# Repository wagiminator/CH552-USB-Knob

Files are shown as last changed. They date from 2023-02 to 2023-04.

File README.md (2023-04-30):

# CH552E USB Knob - Rotary Encoder with USB Interface
The USB Knob is a versatile device that combines the functionality of a rotary encoder with the convenience of a USB interface. It is based on either the CH552E or CH554E microcontroller and is equipped with addressable LEDs, commonly known as NeoPixels. The unique combination of these components makes the USB Knob an ideal choice for a wide range of applications, including volume control for PCs.

One of the standout features of the USB Knob is that it requires no driver installation, making it incredibly easy to use. The device acts as a USB human interface device (HID), meaning that it can be recognized and utilized by most computers without the need for additional software.

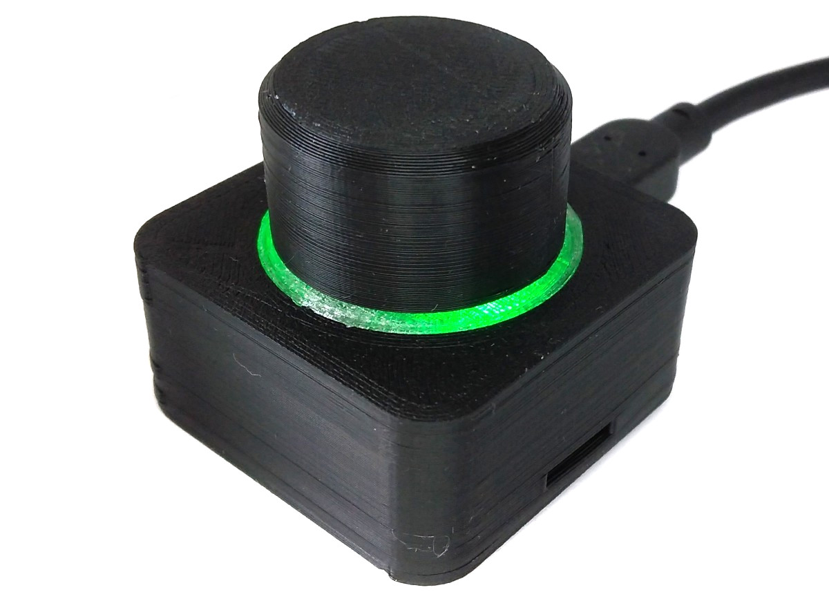
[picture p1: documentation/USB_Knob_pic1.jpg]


# Hardware
## Schematic
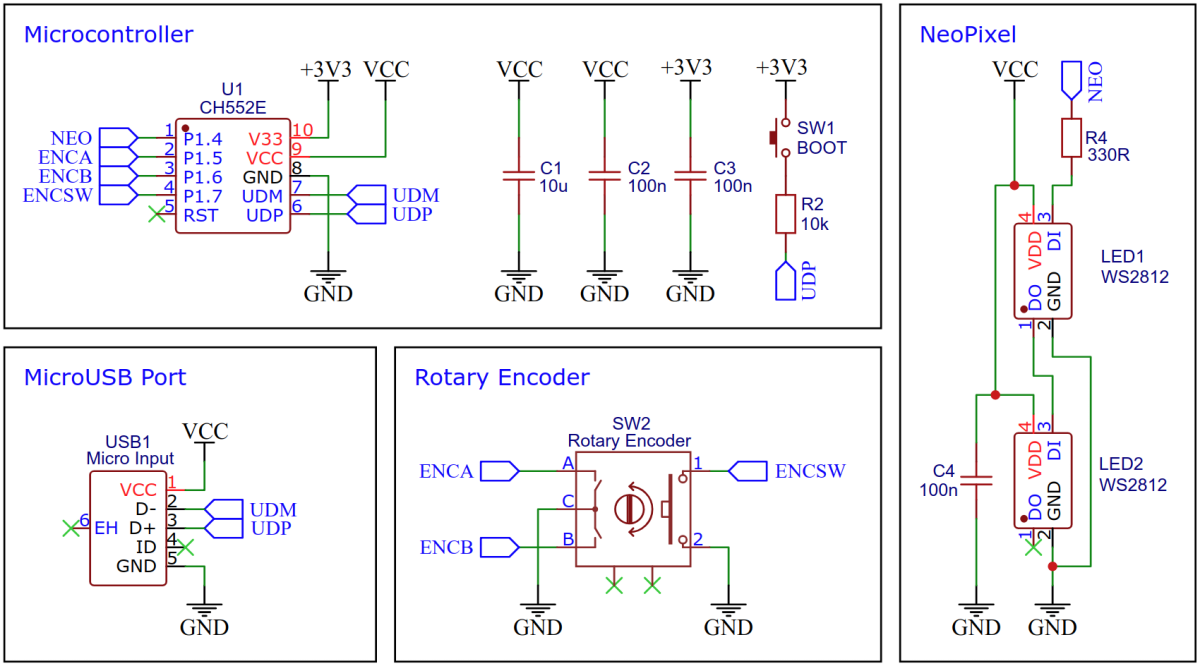
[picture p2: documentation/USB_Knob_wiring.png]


## CH552E 8-bit USB Device Microcontroller
The CH552E is a low-cost, enhanced E8051 core microcontroller compatible with the MCS51 instruction set. It has an integrated USB 2.0 controller with full-speed data transfer (12 Mbit/s) and supports up to 64 byte data packets with integrated FIFO and direct memory access (DMA). The CH552E has a factory built-in bootloader so firmware can be uploaded directly via USB without the need for an additional programming device.

## Building Instructions
1. Take the Gerber files and send them to a PCB manufacturer of your choosing. They will use these files to create the circuit board for your device.
2. Once you have the PCB, you can start soldering the components onto it. Use the BOM (bill of materials) and schematic as a guide to make sure everything is connected correctly.
3. Upload the firmware by following the instructions in the next section (see below).
4. To create the case for your device, use the STL files with your 3D printer. Make sure to use transparent filament for the ring.
5. After printing, secure the PCB to the bottom of the case using four self-tapping M2x5mm screws.
6. Next, glue the ring from the bottom into the circular recess in the top of the case.
7. Finally, assemble the case. Place the knob onto the rotary encoder. Your device is now ready to use!

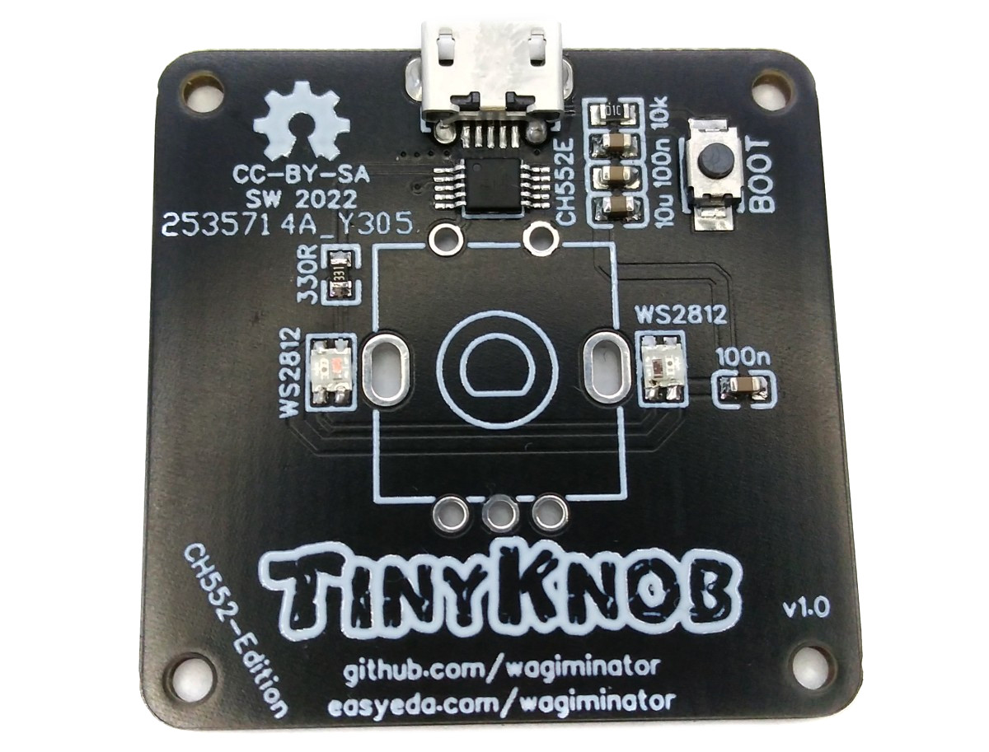
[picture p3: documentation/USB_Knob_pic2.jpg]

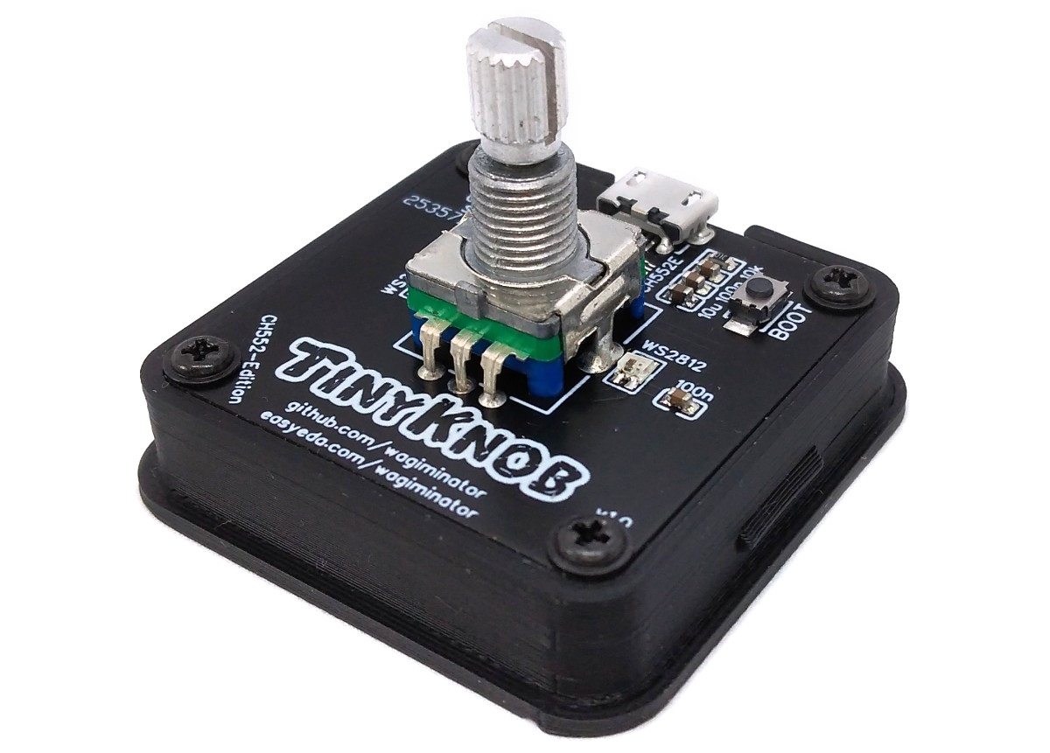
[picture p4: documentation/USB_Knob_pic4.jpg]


# Software
## Firmware Versions
### Volume Knob
This firmware enables the USB Knob to control the volume of your computer. By turning the knob, you can increase or decrease the volume, while pressing the knob will mute or unmute the sound. The device is recognized as a USB HID consumer multimedia keyboard and should work immediately without the need for any driver installation.

### Mouse Wheel Knob
This firmware is designed to transform the USB Knob into a mouse wheel. By rotating the knob, it emulates the movement of a mouse wheel, allowing users to scroll up and down web pages, among other things. Pressing the knob is equivalent to clicking on the mouse wheel or the middle mouse button. The device registers as a USB HID mouse on the computer and should work immediately without the need for driver installation.

### Custom Knob
This firmware is perfect for customizing it according to your own preferences. It allows for the free mapping of USB HID actions to USB Knob events. The firmware is structured and commented in such a way that it should be possible to make adjustments even with basic programming skills. It is designed as a USB HID composite device that combines a keyboard, a mouse, and a game controller.

## Compiling and Installing Firmware
### Preparing the CH55x Bootloader
#### Installing Drivers for the CH55x Bootloader
On Linux you do not need to install a driver. However, by default Linux will not expose enough permission to upload your code with the USB bootloader. In order to fix this, open a terminal and run the following commands:

```
echo 'SUBSYSTEM=="usb", ATTR{idVendor}=="4348", ATTR{idProduct}=="55e0", MODE="666"' | sudo tee /etc/udev/rules.d/99-ch55x.rules
sudo service udev restart
```

For Windows, you need the [CH372 driver](http://www.wch-ic.com/downloads/CH372DRV_EXE.html) (recommended). Alternatively, you can also use the [Zadig Tool](https://zadig.akeo.ie/) to install the correct driver. Here, click "Options" and "List All Devices" to select the USB module, and then install the libusb-win32 driver. To do this, the board must be connected and the CH55x must be in bootloader mode.

#### Entering CH55x Bootloader Mode
A brand new chip starts automatically in bootloader mode as soon as it is connected to the PC via USB. Once firmware has been uploaded, the bootloader must be started manually for new uploads. To do this, the board must first be disconnected from the USB port and all voltage sources. Now press the BOOT button and keep it pressed while reconnecting the board to the USB port of your PC. The chip now starts again in bootloader mode, the BOOT button can be released and new firmware can be uploaded within the next couple of seconds.

Once the USB Knob firmware is installed, the bootloader can also be entered by holding down the rotary encoder switch while connecting the device to the USB port. In this way, the case does not have to be opened when new firmware is to be installed. The NeoPixels will then light up white as long as the device is in bootloader mode (approx. 10 seconds).

### Compiling and Uploading using the makefile
#### Installing SDCC Toolchain for CH55x
Install the [SDCC Compiler](https://sdcc.sourceforge.net/). In order for the programming tool to work, Python3 must be installed on your system. To do this, follow these [instructions](https://www.pythontutorial.net/getting-started/install-python/). In addition [pyusb](https://github.com/pyusb/pyusb) must be installed. On Linux (Debian-based), all of this can be done with the following commands:

```
sudo apt install build-essential sdcc python3 python3-pip
sudo pip install pyusb
```

#### Compiling and Uploading Firmware
- Open a terminal.
- Navigate to the folder with the makefile. 
- Connect the board and make sure the CH55x is in bootloader mode. 
- Run ```make flash``` to compile and upload the firmware. 
- If you don't want to compile the firmware yourself, you can also upload the precompiled binary. To do this, just run ```python3 ./tools/chprog.py firmware.bin```.

### Compiling and Uploading using the Arduino IDE
#### Installing the Arduino IDE and CH55xduino
Install the [Arduino IDE](https://www.arduino.cc/en/software) if you haven't already. Install the [CH55xduino](https://github.com/DeqingSun/ch55xduino) package by following the instructions on the website.

#### Compiling and Uploading Firmware
- Open the .ino file in the Arduino IDE.
- Go to **Tools -> Board -> CH55x Boards** and select **CH552 Board**.
- Go to **Tools** and choose the following board options:
  - **Clock Source:**   16 MHz (internal)
  - **Upload Method:**  USB
  - **USB Settings:**   USER CODE /w 266B USB RAM
- Connect the board and make sure the CH55x is in bootloader mode. 
- Click **Upload**.

# References, Links and Notes
1. [EasyEDA Design Files](https://oshwlab.com/wagiminator)
2. [CH551/552 Datasheet](http://www.wch-ic.com/downloads/CH552DS1_PDF.html)
3. [SDCC Compiler](https://sdcc.sourceforge.net/)
4. [ATtiny85 TinyKnob](https://github.com/wagiminator/ATtiny85-TinyKnob)
5. [CH552E MacroPad mini](https://github.com/wagiminator/CH552-Macropad-mini)
6. [CH552G MacroPad plus](https://github.com/wagiminator/CH552-MacroPad-plus)

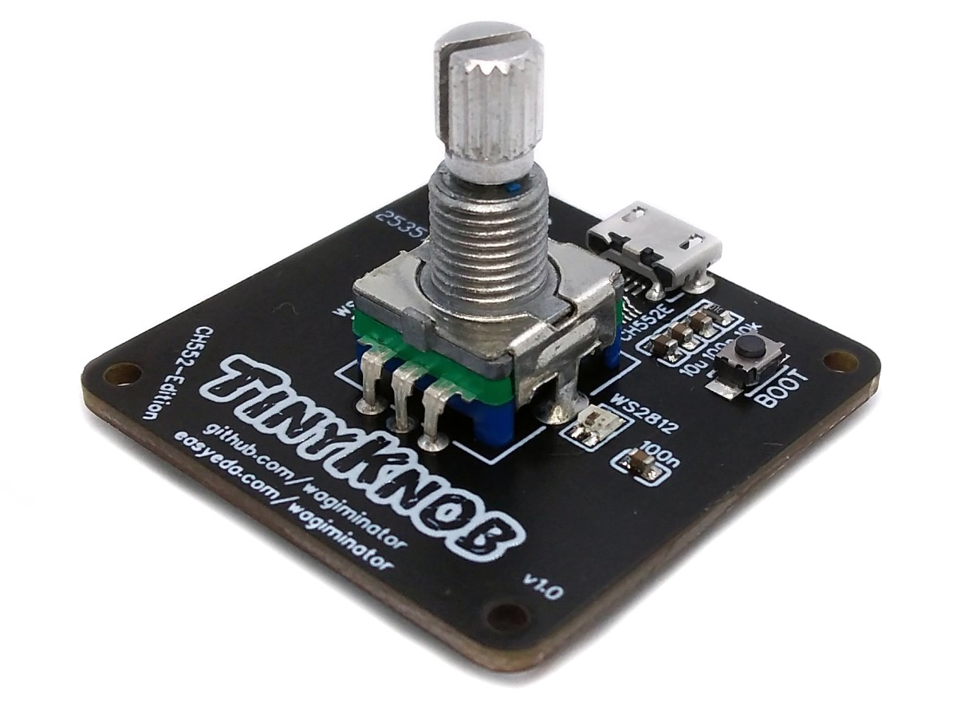
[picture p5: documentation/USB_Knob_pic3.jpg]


# License


This work is licensed under Creative Commons Attribution-ShareAlike 3.0 Unported License. 
(http://creativecommons.org/licenses/by-sa/3.0/)

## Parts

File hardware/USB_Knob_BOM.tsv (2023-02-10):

ID | Name | Designator | Footprint | Quantity | Manufacturer Part | Manufacturer | Supplier | Supplier Part
1 | 10u | C1 | C_0603 | 1 | CL10A106KP8NNNC | SAMSUNG | LCSC | C19702
2 | 100n | C2,C3,C4 | C_0603 | 3 | CC0603KRX7R9BB104 | YAGEO | LCSC | C14663
3 | WS2812 | LED1,LED2 | WS2812-2020 | 2 | WS2812C-2020-V1 | worldsemi | LCSC | C2976072
4 | 10k | R2 | 0603 | 1 | 0603WAF1002T5E | UniOhm | LCSC | C25804
5 | 330R | R4 | 0603 | 1 | 0603WAF3300T5E | UniOhm | LCSC | C23138
6 | BOOT | SW1 | SW-SMD_L4.0-W2.9-LS5.0 | 1 | TS-1185-C-A-B-B | XKB Enterprise | LCSC | C465999
7 | Rotary Encoder | SW2 | ROTARY_ENCODER | 1 | PEC11R-4015F-S0024 | BOURNS | LCSC | C143789
8 | CH552E | U1 | MSOP-10 | 1 | CH552E | WCH(Jiangsu Qin Heng) | LCSC | C967938
9 | Micro Input | USB1 | MINI-USB-SMD_U254-051T-4BH23-S2B | 1 | U254-051T-4BH23-S2B | XKB Enterprise | LCSC | C319164

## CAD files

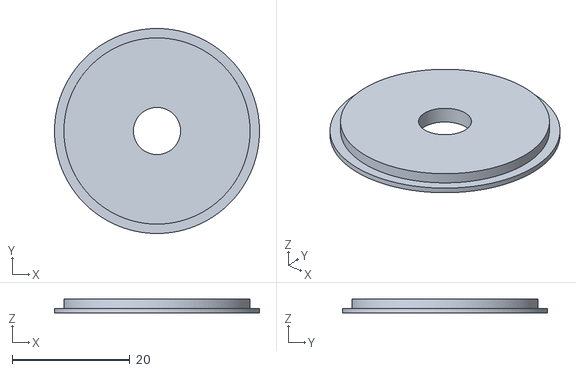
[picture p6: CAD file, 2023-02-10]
3dprint/USB_Knob_case_ring.stl
34.8 x 34.8 x 2.40

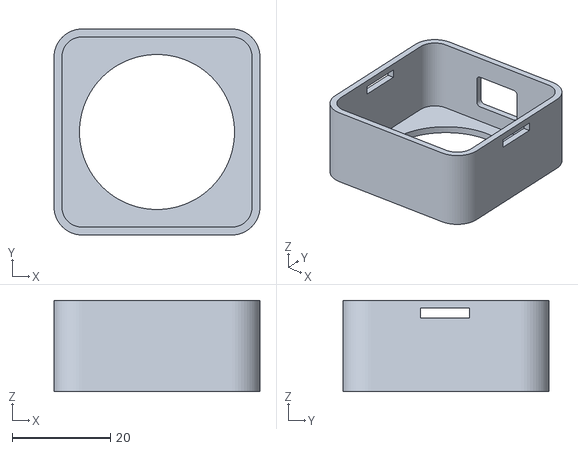
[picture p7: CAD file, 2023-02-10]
3dprint/USB_Knob_case_top.stl
42.0 x 42.0 x 18.6

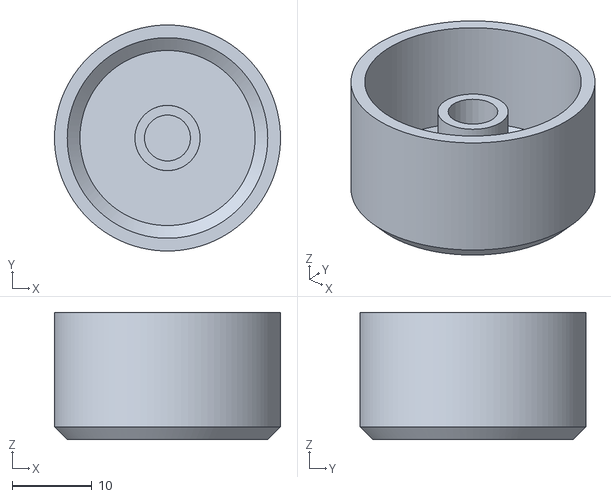
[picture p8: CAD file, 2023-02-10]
3dprint/USB_Knob_knob.stl
28.4 x 28.4 x 16.0

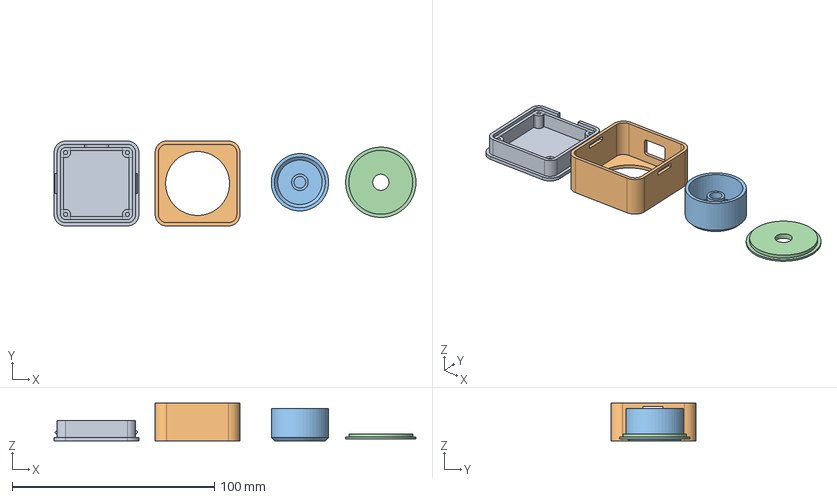
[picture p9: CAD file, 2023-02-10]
3dprint/USB_Knob_case.fcstd
179.0 x 42.0 x 18.6 mm
Boden
Deckel
Knob
LED-Ring

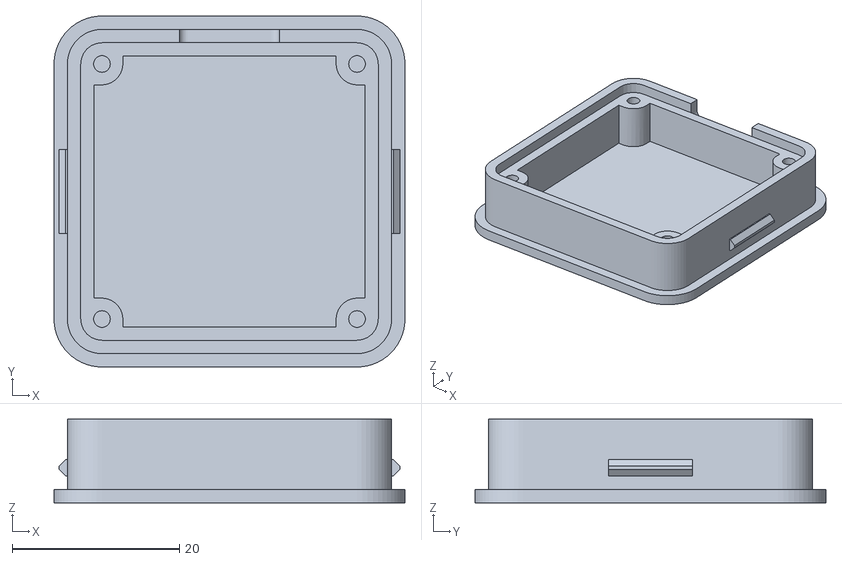
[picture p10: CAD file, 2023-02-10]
3dprint/USB_Knob_case_bottom.stl
42.0 x 42.0 x 10.0

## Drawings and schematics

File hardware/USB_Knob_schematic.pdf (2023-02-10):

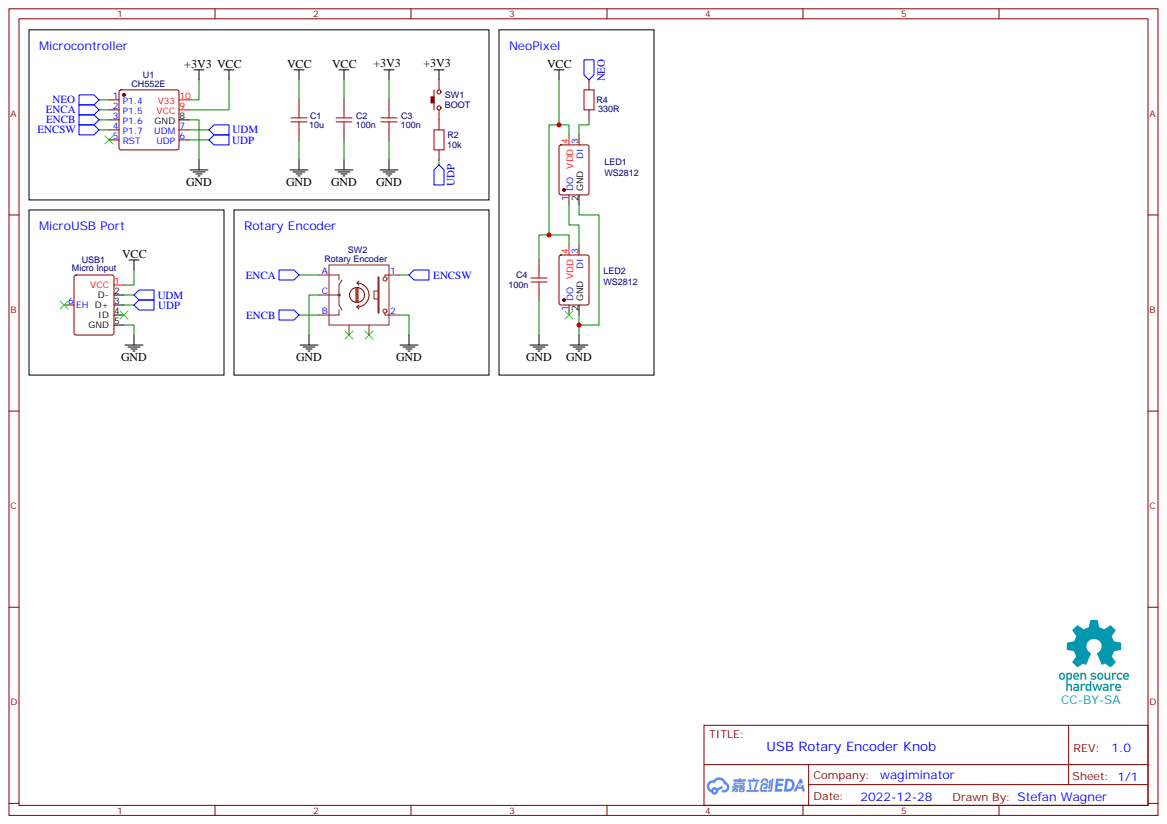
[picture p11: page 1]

Drawn By: Stefan Wagner

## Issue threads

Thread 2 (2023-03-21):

LED Question

smccloud, 2023-03-21:
I'm in the process of printing my second enclosure for these, is it possible to have the Neo Pixels show green if unmuted and red if muted?  They are for my kids and anything to make it easier to see that they are muted/unmuted.

wagiminator, 2023-03-25:
The problem is that the button only toggles the mute state, but doesn't know what this state is itself. This would require feedback from the computer, which is probably not possible without programming a driver. Of course, you can also toggle the LED status by pressing the button, but it cannot be guaranteed whether the LED status and mute status are and remain synchronous.

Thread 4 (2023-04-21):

How to program the knob to do anything I want?

Itz-kavish, 2023-04-21:
Hello! We ordered about 8 of these boards of our class. So far, we have soldered 2 of these boards and made them work. I looked at the github files and there are only two available codes for the knob, one that scrolls and other one code that controls the volume. I wanted to edit the code so it can do anything I want like horizontally scrolling a page, or switching tabs on a browser. Can you please guide me on how to program the knob do it can do anything I want.

wagiminator, 2023-04-23:
I'll make a more versatile and better annotated version of the firmware as soon as I have some free time. You won't be able to avoid a bit of programming though;-)

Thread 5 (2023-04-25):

Volume lowering without turning knob

abigailgrace1017, 2023-04-25:
When I turn the knob to lower or raise my volume I have to turn it by 2 "notches" to get to the next number which is fine. If I only turn the knob one notch it will raise or lower the volume but it seems to get "stuck" wherein the volume continues to lower one number at a time without the knob turning.

abigailgrace1017, 2023-05-02:
Thank you for the information. That may be the problem. I chose the rotary encoder that is listed under hardware but it looks different than the one that you have in the picture.

wagiminator, 2023-05-06:
I bought mine on aliexpress: https://aliexpress.com/item/1005003824684681.html (plum 15mm).

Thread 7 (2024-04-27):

Help with CH552G and CH552E projects

skunkfpv, 2024-04-27:
Hello. I recently have built your macro pad mini, knob, and macro pad plus. So on the mini it accepts the firmware but nothing works but when the 3rd key is pushed it goes into boot loader mode. On the knob the firmware flashes and it appears to be working but in windows it keeps saying device is not recognized and disappears and reappears multiple times. Lastly, on the macro pad plus it is stuck in a boot loop, rebooting every second. Please reply because i want to get these to start working. Thank you a lot, Samuel

wagiminator, 2024-04-27:
Puh, that's hard to tell from a distance with this less information. Let's take the volume knob as an example. How did you compile/upload the firmware? Did it work? If not, what was the error message. What Windows version do you use? What is shown in the device manager?

skunkfpv, 2024-04-27:
Do you have discord? Can we chat on there so I can debug easier?

skunkfpv, 2024-04-28:
I would like to call with my audrino ide on so you can help me debug easier

wagiminator, 2024-04-28:
I apologize, but I don't have Discord, nor do I have sufficient free time for online debugging. Thank you for understanding.

skunkfpv, 2024-04-28:
With the smart knob I wired a usbc plug and it cycles the led correct but none of the microcontrollers are recognized in windows

skunkfpv, 2024-04-29:
Sorry if im not giving enough information. On all of the projects i am getting this error https://cdn.windowsreport.com/wp-content/uploads/2021/12/USB-device-not-recognized-Windows-10-886x590.jpg

wagiminator, 2024-05-01:
Mmmmh, there is a DLY_ms(500) prior to HID_init(). Try to increse the time to DLY_ms(1000) OR remove WDT_start(); AND WDT_reset();

skunkfpv, 2024-05-02:
I just tried both of those and what the boards are doing is they are still having the same issues. They also play the connected and disconnected sounds over and over again until unplugged.

wagiminator, 2024-05-02:
Strange, have you tried it on another computer?

skunkfpv, 2024-05-02:
Yes. It still does the same thing.

skunkfpv, 2024-05-04:
Any more ideas?

wagiminator, 2024-05-04:
I found a PC with Windows 10 Pro, 64-bit, version 22H2 (I'm only using Linux) and re-tested it. It worked without any problems. However, I can not rule out some compatibility issues of the firmware on Windows PCs. Since you don't have problems uploading the firmware I think that this isn't a hardware issue. Unfortunately, since I cannot reproduce the error at the moment, I am currently unable to identify the cause.

skunkfpv, 2024-05-04:
When plugged in it gives me a error message saying that it malfunctions. Are there any modifications in the code that I can make?

skunkfpv, 2024-05-04:
I modified your design @wagiminator and ripped the gnd vcc datap and datan and replaced it with a usb c plug. That's the only mod I did to it. I'm not sure if that modification changed anything

skunkfpv, 2024-05-05:
Could it have anything to do with the device descriptor?

skunkfpv, 2024-05-05:
Also, when I turn the knob it stops changing colors and I think it freezes up. I can't get it to work on an Ubuntu machine either

wagiminator, 2024-05-05:
It shouldn't really be the USB connector. You don't seem to have any issues with uploading the firmware, which also utilizes the USB connection to the microcontroller. If it doesn't even work under Ubuntu, then something's definitely off - but I currently have no idea what. How did you compile the firmware? Have you tried uploading the precompiled .bin file?

skunkfpv, 2024-05-05:
I'm not sure on how to do that. I just used audrino ide

wagiminator, 2024-05-06:
Ah, maybe the Arduino IDE is the problem. Did you make the correct USB-settings in the board options?

Please download WCH's official programming tool: https://www.wch.cn/downloads/WCHISPTool_Setup_exe.html
Try to upload the precompiled binary (.bin file in the software folder) with this tool.

skunkfpv, 2024-05-08:
The .bin worked but not arduino. How do I customize the code inside of the bin file?

skunkfpv, 2024-05-08:
new problem. It sometimes disconnects and reconnects, causing the volume to rapidly increase or decrease by two marks

wagiminator, 2024-05-18:
That can sometimes be due to different versions of the Arduino IDE and Board Package. Unfortunately, I don't remember which version I used for testing back then. Generally, I work without an IDE, so I use the makefile. However, I don't know how to do that on Windows either.

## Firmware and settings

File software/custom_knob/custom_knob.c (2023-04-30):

// ===================================================================================
// Project:   USB Rotary Encoder for CH551, CH552 and CH554 - Custom Control
// Version:   v1.0
// Year:      2023
// Author:    Stefan Wagner
// Github:    https://github.com/wagiminator
// EasyEDA:   https://easyeda.com/wagiminator
// License:   http://creativecommons.org/licenses/by-sa/3.0/
// ===================================================================================
//
// Description:
// ------------
// Customize your USB Rotary Encoder Knob.
//
// References:
// -----------
// - Blinkinlabs: https://github.com/Blinkinlabs/ch554_sdcc
// - Deqing Sun: https://github.com/DeqingSun/ch55xduino
// - Ralph Doncaster: https://github.com/nerdralph/ch554_sdcc
// - WCH Nanjing Qinheng Microelectronics: http://wch.cn
// - ATtiny85 TinyKnob: https://github.com/wagiminator/ATtiny85-TinyKnob
//
// Compilation Instructions:
// -------------------------
// - Chip:  CH551, CH552 or CH554
// - Clock: 16 MHz internal
// - Adjust the firmware parameters in src/config.h if necessary.
// - Customize the macro functions in the corresponding section below.
// - Make sure SDCC toolchain and Python3 with PyUSB is installed.
// - Press BOOT button on the board and keep it pressed while connecting it via USB
//   with your PC.
// - Run 'make flash' immediatly afterwards.
// - To compile the firmware using the Arduino IDE, follow the instructions in the 
//   .ino file.
//
// Operating Instructions:
// -----------------------
// - Costomize your rotary encoder knob below in this firmware.
// - Connect the board via USB to your PC. It should be detected as a HID composite
//   device with keyboard, mouse and game controller interface.
// - Turn the rotary encoder or press the encoder switch.
// - To enter bootloader hold down the rotary encoder switch while connecting the 
//   device to USB. The NeoPixels will light up white as long as the device is in 
//   bootloader mode (about 10 seconds).


// ===================================================================================
// Libraries, Definitions and Macros
// ===================================================================================

// Libraries
#include "src/config.h"                   // user configurations
#include "src/system.h"                   // system functions
#include "src/delay.h"                    // delay functions
#include "src/neo.h"                      // NeoPixel functions
#include "src/usb_composite.h"            // USB HID composite functions

// Prototypes for used interrupts
void USB_interrupt(void);
void USB_ISR(void) __interrupt(INT_NO_USB) {
  USB_interrupt();
}

// ===================================================================================
// Macro Functions which associate Actions with Events (Customize your USB Knob here!)
// ===================================================================================
//
// The list of available USB HID functions can be found in src/usb_composite.h

// Rotary encoder example -> volume control knob
// ---------------------------------------------

// Define action(s) if encoder was rotated clockwise
inline void ENC_CW_ACTION() {
  CON_press(CON_VOL_UP);                              // press VOLUME UP key
}

// Define action(s) after encoder was rotated clockwise
inline void ENC_CW_RELEASED() {
  CON_release();                                      // release VOLUME UP KEY
}

// Define action(s) if encoder was rotated counter-clockwise
inline void ENC_CCW_ACTION() {
  CON_press(CON_VOL_DOWN);                            // press VOLUME DOWN key
}

// Define action(s) after encoder was rotated counter-clockwise
inline void ENC_CCW_RELEASED() {
  CON_release();                                      // release VOLUME DOWN KEY
}

// Define action(s) if encoder switch was pressed
inline void ENC_SW_PRESSED() {
  CON_press(CON_VOL_MUTE);                            // press VOLUME MUTE key
}

// Define action(s) if encoder switch was released
inline void ENC_SW_RELEASED() {
  CON_release();                                      // release VOLUME MUTE key
}

// ===================================================================================
// Main Function
// ===================================================================================
void main(void) {

  // Variables
  uint8_t i;                              // temp variable
  uint8_t cnt = 1;                        // hue cycle counter
  uint8_t hue = 0;                        // hue cycle value
  __bit isSwitchPressed = 0;              // state of rotary encoder switch

  // Setup
  NEO_init();                             // init NeoPixels
  CLK_config();                           // configure system clock
  DLY_ms(10);                             // wait for clock to settle

  // Enter bootloader if encoder switch is pressed
  if(!PIN_read(PIN_ENC_SW)) {             // encoder switch pressed?
    for(i=6; i; i--) NEO_sendByte(127);   // light up all pixels
    BOOT_now();                           // enter bootloader
  }

  // Init USB keyboard
  HID_init();                             // init USB HID consumer keyboard
  DLY_ms(500);                            // wait for Windows...
  WDT_start();                            // start watchdog timer

  // Loop
  while(1) {
    if(!PIN_read(PIN_ENC_A)) {                            // encoder turned ?
      if(PIN_read(PIN_ENC_B)) {                           // clockwise ?
        ENC_CW_ACTION();                                  // take proper action
        DLY_ms(5);                                        // debounce
        ENC_CW_RELEASED();                                // take proper action
      }
      else {                                              // counter-clockwise ?
        ENC_CCW_ACTION();                                 // take proper action
        DLY_ms(5);                                        // debounce
        ENC_CCW_RELEASED();                               // take proper action
      }
      while(!PIN_read(PIN_ENC_A));                        // wait until next detent
    } 
    else {
      if(!isSwitchPressed && !PIN_read(PIN_ENC_SW)) {     // switch previously pressed?
        ENC_SW_PRESSED();                                 // take proper action
        isSwitchPressed = 1;
      }
      else if(isSwitchPressed && PIN_read(PIN_ENC_SW)) {  // switch previously released?
        ENC_SW_RELEASED();                                // take proper action
        isSwitchPressed = 0;                              // update switch state
      }
    }
    if(!--cnt) {                                          // time to cycle hue?
      NEO_writeHue(hue, 0); NEO_writeHue(hue, 0);         // set NeoPixels hue value
      if(!hue--) hue = 191;                               // cycle hue value
    }
    DLY_ms(1);                                            // slow down a little
    WDT_reset();                                          // reset watchdog
  }
}

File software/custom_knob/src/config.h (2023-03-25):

// ===================================================================================
// User Configurations for CH552E USB Rotary Encoder
// ===================================================================================

#pragma once

// Pin definitions
#define PIN_NEO             P14       // pin connected to NeoPixel
#define PIN_ENC_A           P15       // pin connected to rotary encoder A
#define PIN_ENC_B           P16       // pin connected to rotary encoder B
#define PIN_ENC_SW          P17       // pin connected to rotary encoder switch

// NeoPixel configuration
#define NEO_GRB                       // type of pixel: NEO_GRB or NEO_RGB

// USB device descriptor
#define USB_VENDOR_ID       0x1189    // VID
#define USB_PRODUCT_ID      0x8890    // PID
#define USB_DEVICE_VERSION  0x0100    // v1.0 (BCD-format)

// USB configuration descriptor
#define USB_MAX_POWER_mA    50        // max power in mA 

// USB descriptor strings
#define MANUFACTURER_STR    'w','a','g','i','m','i','n','a','t','o','r'
#define PRODUCT_STR         'T','i','n','y','K','n','o','b'
#define SERIAL_STR          'C','H','5','5','2','x','H','I','D'
#define INTERFACE_STR       'H','I','D','-','K','e','y','b','o','a','r','d'
